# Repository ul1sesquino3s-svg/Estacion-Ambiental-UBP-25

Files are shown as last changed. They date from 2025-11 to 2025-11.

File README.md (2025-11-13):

# Estacion-Ambiental-UBP-25

Repositorio del proyecto de Lab-I con Arduino UNO: Estación Ambiental Inteligente con sensores y módulos

Integrantes del proyecto: Ignacio Alzabé, Donato Doebbeling, Ulises Carlos Quiñones, Juan Manuel Servadei

Profesores:

Teórico: Ing. Martín Salamero

Práctico: Prof. Aguero y Prof. Escudero

## **Cosas Importantes**

**Lectura de los archivos CSV**
Cada linea tiene la fecha y la hora, y los números que hay corresponden a la temperatura, humedad del aire, luminosidad y humedad

de la tierra, respectivamente.

**App Bluetooth**

Se abre la app, debe elegirse el módulo previamente emparejado llamada *GORDATO*, luego se presiona "Conectar" y se espera un minuto

hasta que se envien por primera vez los datos en el módulo.

**LCD I2C**

Todos los sensores mostrarán 0 en sus lecturas durante el primer minuto; esto forma parte del funcionamiento esperado, ya que

los datos se actualizan cuando se cargan en el archivo csv, que ocurre cada 60 segundos.

**Contenido del Repositorio**

Presentación utilizada durante la exposición

Archivo CSV del día 22 de octubre, uno de los días los cuales se hizo la prueba de 48hs.

Informe completo del proyecto

Bitácoras de todo el progreso del proyecto

Código en .ino del proyecto y backup en .txt

Archivo STL de la carcasa creada para el proyecto

README

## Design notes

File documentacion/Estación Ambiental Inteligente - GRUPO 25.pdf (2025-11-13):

Proyecto Arduino: Estación Ambiental Inteligente

GRUPO 25: Ignacio Alzabé, Donato Doebbeling, Ulises Quiñones, Juan Manuel Servadei

Prof. Martín Salamero

Universidad Blas Pascal

14 de noviembre de 2025

ÍNDICE

INTRODUCCIÓN

Nuestro objetivo de todo el semestre fue crear una estación ambiental propia, con código propio y aprendiendo paso a paso en el camino. Al igual que los demás grupos, los materiales con los que iniciamos fueron:
- Arduino UNO
- Protoboard
- Cables macho-macho, hembra-hembra, macho-hembra
- Fotorresistor LDR
- Sensor DHT11 (Humedad y Temperatura)
- Sensor opcional de humedad de la tierra
- Clock RTC DS1302
- Resistencias de 1k ohm
- Pantalla LCD I2C 16x2
- Lector de tarjetas SD
- Módulo Bluetooth HC-05

Nuestra plataforma de organización fue Microsoft Teams, donde fuimos escribiendo nuestras bitácoras día a día y en los Mensajes Directos están todas nuestras iteraciones de código, hasta las más mínimas.

En el tiempo dado, pudimos armar, codificar, probar y finalizar un prototipo completo de una Estacion Ambiental Inteligente, donde se registran datos como: Temperatura, Humedad del suelo y de la tierra (donde sea que se lo plante al sensor), luminosidad, y grabar todos los datos en una tarjeta SD con una duración estimada de 5 años de almacenamiento.

DESARROLLO
Información de sensores
Fotorresistor LDR
Su nombre proviene del inglés y significa resistor dependiente de la luz. Esto significa que el valor de la resistencia depende de la luz que esté recibiendo. Gracias a esto, se puede transformar con Arduino IDE el valor que recibe a un porcentaje para medir la luz en un ambiente, por ejemplo. También puede usarse para detectar cuando pasan personas por una puerta. Tienen solo dos patas, por lo que deben conectarse en serie con otras resistencias.

Sensor DHT11
Es uno de los sensores más usados y conocidos para trabajar con Arduino. Tiene una alta estabilidad y fiabilidad, pero una de sus desventajas es que sus patas son muy finas. Esto puede llevar a problemas en la señal si no se conectan adecuadamente. Mide temperatura y humedad del aire, y transmite ambos datos por pin analógico. Tiene una versión con PCB, que integra una resistencia pull up. Necesita una librería para configurarlo.

Sensor de humedad del suelo
Comprado en MercadoLibre, tiene dos electrodos y un módulo con led de conexión y de alta humedad integrado. Funciona midiendo la capacidad de la tierra para transmitir electricidad, y gracias a eso, calcular el agua presente en el suelo y convertirlo a voltaje. Está conectado a una salida analógica.

Reloj RTC DS1302
Tiene la capacidad de llevar el tiempo con el poder desconectado gracias a una pila CR2025 o CR2032. Necesita una librería para configurarlo.

Pantalla I2C 16x2
Muestra todos los datos de los sensores y la fecha y hora en el Arduino. Tiene un módulo i2c conectado detrás para reducir la cantidad de pines necesarios. En nuestro caso particular, la dirección donde se encuentra es 0x26, pero la más común es 0x27.

Lector de tarjetas SD
Gracias a la librería SD de arduino, puede cargar los datos de los sensores en un archivo csv cada cierta cantidad de tiempo. En nuestro caso, cada minuto.

Módulo Bluetooth HC-05
Módulo con SLAVE y MASTER, usado para transmitir datos desde el Arduino hasta nuestra app para celulares creada en Mit App Inventor.

Primeras versiones del código

Lo primero fue la investigación; aplicando lo que nos habían enseñado hasta ahora, conectamos los sensores a los cables y estos a los distintos puertos del Arduino. Revisamos en internet, y en páginas de los sensores, distintos códigos de prueba para verificar el funcionamiento de cada uno de los mismos.
La primera dificultad que nos encontramos fue cuando detectamos que el DHT11 no funcionaba, creímos que fue porque estaba defectuoso o dañado, por lo que fue reemplazado por otro comprado fuera del laboratorio. Este nuevo sensor, a diferencia del anterior, requería dos resistencias externas para funcionar, que agregamos en la protoboard para realizar la señal.

Con el nuevo sensor, escribimos un código inicial que hacía esto:
- Iniciaba el LCD y el sensor DHT11
- Leía los valores de temperatura y humedad cada 5 segundos.
- Mostraba alternativamente en el LCD dichos valores, con mensajes simples
- Implementa una verificación de errores para evitar mostrar valores inválidos (isnan)

Este prototipo nos permitió validar que el Arduino pudiese interactuar correctamente con el sensor y el display.

Código inicial

#include <Wire.h>

#include <LiquidCrystal_I2C.h> #include <DHT.h>

#define DHTPIN 5

#define DHTTYPE DHT11

DHT dht(DHTPIN, DHTTYPE);

LiquidCrystal_I2C lcd(0x26, 16, 2);

void setup() {
lcd.init();
lcd.backlight();
dht.begin();
}

void loop() {

delay(5000);
float h = dht.readHumidity();
float t = dht.readTemperature();

if (isnan(h) || isnan(t)) {
lcd.print("Error obteniendo los datos del sensor DHT11"); return;
}

lcd.clear();
lcd.setCursor(0, 0);
lcd.print("Humedad:");
lcd.setCursor(10, 0);
lcd.print(h);
lcd.print("%");
delay(5000);

lcd.clear();
lcd.setCursor(0, 0);
lcd.print("Temp:");
lcd.setCursor(10, 1);
lcd.print(t);
lcd.print(" C");
delay(5000);
}

Explicacion del codigo

#include <Wire.h>

#include <LiquidCrystal_I2C.h>

#include <DHT.h>

- Wire.h : permite la comunicación 12C entre el Arduino y otros dispositivos
- LiquidCrystal_I2C.h : Controla la pantalla LCD utilizando solo dos pines mediante I2C.
- DHT.h : Permite leer datos del sensor DHT11

Definición del sensor:

#define DHTPIN 5

#define DHTTYPE DHT11

DHT dht(DHTPIN, DHTTYPE);
- Acá se define el pin digital 5 como el pin de datos del sensor.

- Se indica que se está utilizando un DHT11
- Se crea un objeto “dht” para manejar las lecturas del sensor

Inicializacion del display y el sensor:

LiquidCrystal_I2C lcd(0x26, 16, 2);

void setup() {
lcd.init(); | // Inicializa la pantalla
lcd.backlight(); | // Enciende la luz de fondo del LCD
dht.begin(); | // Inicia el sensor DHT11
}
- El LCD tiene dirección “0x26” y es de 2 filas por 16 columnas.
- En setup() se inicializan ambos periféricos para que estén listos para usarse

Lógica principal (Loop):

void loop() {
delay(5000); // Espera 5 segundos entre cada ciclo
- Se utiliza una espera inicial para evitar lecturas demasiado seguidas
float h = dht.readHumidity(); | // Lee la humedad (%)
float t = dht.readTemperature(); | // Lee la temperatura (°C)
- Las lecturas se almacenan como variables Float para poder mostrar los decimales

if (isnan(h) || isnan(t)) {
lcd.print("Error obteniendo los datos del sensor DHT11");
return;
}
- Si alguna lectura falla, se muestra un mensaje de error y se interrumpe el ciclo actual.

float hic = dht.computeHeatIndex(t, h);

- A pesar de que no se muestre en pantalla, se calcula el índice de calor usando la temperatura y la humedad

Mostrar humedad:

lcd.clear();
lcd.setCursor(0, 0);
lcd.print("Humedad:");
lcd.setCursor(10, 0);
lcd.print(h);
lcd.print("%");
delay(5000);
- Limpia la pantalla, escribe “Humedad:” y luego muestra el valor leído seguido de “%”
- Espera 5 segundos antes de cambiar la pantalla

Mostrar temperatura:

lcd.clear();
lcd.setCursor(0, 0);
lcd.print("Temp:");
lcd.setCursor(10, 1);
lcd.print(t);
lcd.print(" C");
delay(5000);
}
- Limpia la pantalla, muestra “Temp:” y el valor de temperatura seguido de “°C”
- Espera 5 segundos antes de reiniciar el bucle

Etapa 2

Ese mismo día, avanzamos hubo una mejora del código. Incorporaba un sensor de luz analogico (LDR) conectado al pin A0

En esta versión del código se mantuvo el DHT11 para leer la temperatura y humedad, se agregó una lectura analógica desde el LDR, usando “analogRead(A0)”. Se implementó la función map() para convertir el valor leído (entre 0 y 1023) Se programó que el LCD muestre tres variables secuencialmente (Humedad, Temperatura y Nivel de luz)

Esta versión fue importante porque empezamos a implementar múltiples sensores y a experimentar con la secuencia de visualización en pantalla.

Segundo código
#include <Wire.h>

#include <LiquidCrystal_I2C.h> #include <DHT.h>

#define DHTPIN 5

#define DHTTYPE DHT11

DHT dht(DHTPIN, DHTTYPE);
const int sensorluz = A0;

LiquidCrystal_I2C lcd(0x26, 16, 2);

void setup() {
lcd.init();
lcd.backlight();
dht.begin();
}

void loop() {
delay(1000);

float h = dht.readHumidity();
float t = dht.readTemperature();

int valorluz = analogRead(sensorluz);
int porcentajeluz = map(valorluz, 0, 1023, 0,100);

if (isnan(h) || isnan(t)) {
lcd.print("Error obteniendo los datos del sensor DHT11"); return;
}

float hic = dht.computeHeatIndex(t, h);

lcd.clear();
lcd.setCursor(0, 0);
lcd.print("Humedad:");
lcd.setCursor(10, 0);
lcd.print(h);
lcd.print("%");
delay(5000);

lcd.clear();
lcd.setCursor(0, 0);

lcd.print("Temp:");
lcd.setCursor(10, 0);
lcd.print(t);
lcd.print(" C");
delay(5000);

lcd.clear();
lcd.setCursor(0, 0);
lcd.print("Luz:");
lcd.setCursor(10, 0);
lcd.print(porcentajeluz);
lcd.print("%");
delay(1000);
}

Explicacion del codigo (Solo lo añadido)
int valorluz = analogRead(sensorluz);
- Se realiza una lectura analogica desde el pin A0, que entregas valores entre 0 y 1023
int porcentajeluz = map(valorluz, 0, 1023, 0, 100);
- Se usa la función map() para transformar la lectura a un porcentaje inverso
- 0%: máxima oscuridad
- 100%: máxima luz

lcd.clear();
lcd.setCursor(0, 0);
lcd.print("Luz:");
lcd.setCursor(10, 0);
lcd.print(porcentajeluz);
lcd.print("%");
delay(1000);
- Se agregó una tercera pantalla al ciclo de visualización
- Muestra el porcentaje de luz y luego se espera 1 segundo antes de reiniciar el bucle

Etapa 3

En esta nueva versión del código, se incorporó el modulo RTC DS1302, que nos permitió disponer de una referencia horaria confiable y permanente, independientemente del estado de alimentación del Arduino.

Además, reorganizamos completamente la forma en el que se muestran los datos en la pantalla LCD, dividiéndose en dos grupos de variables, por un lado las variables de los sensores y por el otro la fecha y hora , que estos se muestran en la pantalla LCD y alternan sus valores cada 5 segundos.

Código tres, RTC y organización

// BETA ESTACION AMBIENTAL

#include <Wire.h>

#include <LiquidCrystal_I2C.h>

#include <DHT.h>

#include <RtcDS1302.h>

#define DHTPIN 5

#define DHTTYPE DHT11

DHT dht(DHTPIN, DHTTYPE);

const int sensorluz = A0;

const int sensorhumt = A2;

LiquidCrystal_I2C lcd(0x26, 16, 2);

ThreeWire myWire(4, 5, 2); // IO, SCLK, CE

RtcDS1302<ThreeWire> Rtc(myWire);

// ---- control de tiempos ----unsigned long previousMillisRTC = 0;

unsigned long previousMillisSensors = 0;

const unsigned long intervalRTC = 1000; // refrescar hora cada 1s

const unsigned long intervalSensors = 5000; // alternar sensores cada 5s

bool mostrarGrupo1 = true;

void setup() {

Serial.begin(9600);

lcd.init();

lcd.backlight();

dht.begin();

delay(2000);

// Inicializar el RTC

Rtc.Begin();

delay(1000);

// Setear fecha/hora de compilación (solo como ejemplo)

RtcDateTime compiled = RtcDateTime(__DATE__, __TIME__);

Rtc.SetDateTime(compiled);

if (Rtc.GetIsWriteProtected()) {

Rtc.SetIsWriteProtected(false);

}

}

void loop() {

unsigned long currentMillis = millis();

// --- actualizar hora cada 1s ---

if (currentMillis - previousMillisRTC >= intervalRTC) {

previousMillisRTC = currentMillis;

RtcDateTime now = Rtc.GetDateTime();

printTime_LCD(now);

}

// --- alternar sensores cada 5s ---

if (currentMillis - previousMillisSensors >= intervalSensors) {

previousMillisSensors = currentMillis;

// limpiar primera línea

lcd.setCursor(0, 0);

lcd.print(" | ");

if (mostrarGrupo1) {

// Grupo 1: humedad suelo + luz

int valorluz = analogRead(sensorluz);

int porcentajeluz = map(valorluz, 0, 1023, 0, 100);

int valorhumedadt = analogRead(sensorhumt);

int porcentaje hunt = map(valorhumedadt, 365, 1023, 100, 0);

lcd.setCursor(0, 0);

lcd.print("HS:");

lcd.print(porcentajehumt);

lcd.print("%");

lcd.setCursor(7, 0);

lcd.print("Luz:");

lcd.print(porcentajeluz);

lcd.print("%");

} else {

// Grupo 2: temperatura + humedad aire

float h = dht.readHumidity();

float t = dht.readTemperature();

lcd.setCursor(0, 0);

lcd.print("T:");

lcd.print((int)t); // entero para que entre

lcd.print((char)223); // símbolo de grados °

lcd.print("C");

lcd.setCursor(8, 0);

lcd.print("HA:");

lcd.print((int)h);

lcd.print("%");

}

mostrarGrupo1 = !mostrarGrupo1; // alternar

}

}

void printTime_LCD(const RtcDateTime& dt) {

char datestring[9]; // HH:MM:SS

snprintf_P(datestring, sizeof(datestring),

PSTR("%02u:%02u:%02u"),

dt.Hour(), dt.Minute(), dt.Second());

lcd.setCursor(7, 1);

lcd.print(datestring);

}

Explicacion del codigo, solo lo nuevo:

#include <RtcDS1302.h>

- Se utiliza la librería RtcDs1302.h

ThreeWire myWire(4, 5, 2); // IO, SCLK, CE RtcDS1302<ThreeWire> Rtc(myWire);

- Se utiliza la interfaz “TrheeWire” para manejar el reloj de tiempo real.

RtcDateTime compiled = RtcDateTime(__DATE__, __TIME__); Rtc.SetDateTime(compiled);
- En el setup(), se carga la fecha/hora de compilación como valor inicial
- Esto se hace una sola vez para sincronizar el reloj interno, luego queda funcionando de forma autónoma

printTime_LCD(now);

- Cada segundo, se actualiza el reloj usando esa línea
- El tiempo se muestra en la segunda fila del LCD con el formato HH:MM:SS

Ciclo de visualización alternado

bool mostrarGrupo1 = true;

- Se alternan dos grupos de datos en la primera fila de LCD, cada 5 segundos:
- Grupo 1:
- HS: Humedad del suelo
- Luz: Nivel de luz
- Grupo 2:
- T: Temperatura ambiente
- HA: Humedad ambiente
- Se utilizó una bandera booleana “mostrarGrupo1” para alternar entre ambos grupos

Este diseño simplifica la interfaz y permite mostrar mas informacion con un solo display de 16x2 sin saturar

Control por temporizadores:

if (currentMillis - previousMillisRTC >= intervalRTC)

- Se reemplazó el uso de delau() por un control manual del tiempo con millis(), lo que permite ejecutar tareas en paralelo sin bloquear el programa
- Esto fue clave para poder actualizar sensores y reloj a diferentes intervalos sin conflictos.

Con esta versión logramos una visualización organizada. Integramos el RTC DS1302 que nos permitió que el proyecto de un salto de calidad: ahora puede registrar eventos o variables con una referencia temporal real, esencial para la futura integración con la tarjeta SD y el registro de datos históricos.

Etapa 4

En esta etapa del desarrollo, implementamos el sensor de humedad y avanzamos hacia uno de los objetivos fundamentales del proyecto: registrar los datos medidos en archivos CSV, almacenados en una tarjeta microSD, con su respectiva marca temporal obtenida del módulo RTC.

Este paso permitió que la estación ambiental ya no solo mostrará datos en tiempo real, sino que pudiera registrarlos de forma histórica para su posterior análisis.

Agregados nuevos

Inicialización del módulo SD

#include <SD.h>

#include <SPI.h>

if (!SD.begin(10)) {
Serial.println("Fallo al inicializar SD.");
return;
}
- Se utilizó la librería SD.h para manejar el almacenamiento
- El módulo se inicializa en el pin 10
- Si la tarjeta no es detectada correctamente, el programa muestra un mensaje aborta la operación

Creación del nombre de archivo

sprintf(nombreArchivo, "LOG_%04u%02u%02u.CSV", ahora.Year(), ahora.Month(), ahora.Day());

- Se crea un archivo diferente por cada día de funcionamiento
- El nombre tiene el formato “LOG_AAAAMMDDD.CSV”

Formateo de timestamp con RTC

sprintf(tiempoBuffer, "%04u/%02u/%02u %02u:%02u:%02u", ...);

- Se construye una cadena con la fecha y hora actual.
- Se almacena en “tiempoBuffer” que luego se utiliza tanto para mostrar en LCD como para registrar en el archivo

Lectura de sensores y escrituras en SD

sprintf(cargardatos, "%s,%d,%d,%d,%d", tiempoBuffer, t, h, porcentajeluz, porcentajehumedadt);
myFile = SD.open(nombreArchivo, FILE_WRITE);
- Cada 60 segundos se actualizan las lecturas de los sensores
- Los valores se combinan con el timestamp en una línea CSV.
- La línea se escribe en el archivo correspondiente al día actual

Visualización dual mejorada

- Ahora cada 3 segundos la pantalla LCD alterna entre:
- Pantalla 1: Muestra las cuatro variables
- Pantalla 2: Muestra la fecha y la hora

Con esta versión alcanzamos un prototipo casi completo y autónomo, capaz de medir, mostrar y registrar datos ambientales de forma continua y confiable.
Etapa final, finalizacion del código

En esta versión final, se completó el ciclo completo del proyecto: Medir,mostrar,registrar y transmitir datos ambientales en tiempo real, de forma autónoma y continua. También, se hizo una aplicación en “MIT App Inventor” para que pueda recibir los datos que da el Arduino.

La principal novedad es la integración del módulo Bluetooth HC-05, que permite enviar los datos a un celular que tenga la aplicación que desarrollamos. Esto transforma la estación en un sistema de monitoreo en vivo.

Código final

Visible en repositorio de GIT

Lo nuevo

#include <SoftwareSerial.h> SoftwareSerial BT(7, 8); // RX, TX

BT.begin(9600);
BT.println("HC-05 listo");
- Se utiliza la librería “SoftwareSerial” para crear un puerto serie adicional en los pines 7 y 8
- Al encender la estación, se envía un mensaje de bienvenida a la app
- Este mensaje inicial también sirve para comprobar que la conexión está activa

BT.println(cargardatos);

- Esto permite visualizar en tiempo real las variables ambientales sin tener que abrir el archivo o conectar el Arduino a una PC.
- Si ocurre un error al guardar la tarjeta SD, también se avisa por bluetooth

BT.println("ERROR_SD");

- Esto mejora la detección de fallas

Mejoras finales

Se implementó una función llamada “abrirArchivoNuevo()” que verifica si el archivo diario está abierto y lo reabre automáticamente si es necesario. También, se añadieron mecanismos de recuperación ante fallos en la tarjeta SD, como un reinicio del bus SPI, intentar abrir el archivo de nuevo y por último un Fallback con mensaje de error.

A lo largo de las distintas etapas, el código evolucionó desde una simple lectura de sensores hasta un sistema integrado de monitoreo ambiental inteligente, con funcionalidades:
- Sensor de temperatura y humedad del aire
- Sensor de luz
- Sensor de humedad del suelo

- Registro de datos en tarjeta SD
- Visualización cíclica en pantalla LCD
- Control de fecha/hora con RTC DS1302
- Comunicación Bluetooth en tiempo real
Se logró una estación autónoma capaz de operar más de 48 horas sin intervención.

CONCLUSIÓN

A lo largo del proyecto, nuestro grupo logró desarrollar una estación de monitoreo ambiental inteligente completamente funcional, capaz de operar de forma autónoma durante más de 48 horas. El proceso de desarrollo no fue lineal. Tuvimos que investigar sobre todo los sensores, como funcionan y cómo se conectan. Fue una prueba, error y corrección constante, y un fuerte trabajo colaborativo que fue moldeando el producto final.

Comenzamos con un código muy simple que solo leía temperatura y humedad del aire (Con el DHT11), y lo mostraba por la pantalla. A medida que fuimos investigando y aprendiendo de los componentes, fuimos incorporando nuevas funcionalidades claves, como la lectura de luz, humedad del suelo, gestión horaria con un reloj RTC, guardado automático de datos en archivos CSV y, finalmente, comunicación en tiempo real por Bluetooth hacia una aplicación móvil diseñada por nosotros mismos.

Además de integrar varios sensores y módulos distintos, aplicamos principios de programación eficientes, tales como el uso de millis() para evitar bloqueos, estructuras condicionales para la rotación de pantallas, verificación de errores en sensores y tarjetas SD, y funciones especificas como “abrirArcvhioNuevo()” para lograr un sistema robusto y tolerante a fallos.

El resultado es un dispositivo modular, portátil y confiable, capaz de medir en simultáneo cinco variables distintas, como la temperatura, humedad del aire, humedad del suelo, nivel de luz y fecha/hora. Todos estos datos se visualizan, registran y transmiten sin necesidad de una intervención humana.

Este proyecto nos permitió aplicar lo aprendido en clase y enfrentarnos a problemas reales que nos obligaron a buscar soluciones, debatir ideas y trabajar como equipo. Más allá de lo técnico, fue una experiencia formativa que refuerza nuestras habilidades en programación, electrónica, diseño de sistemas y documentación.

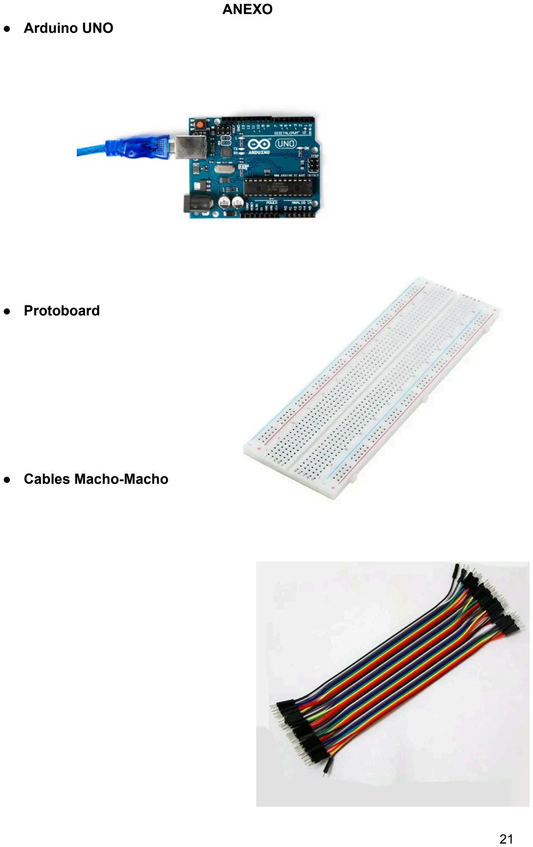
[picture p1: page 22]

ANEXO
- Arduino UNO
- Protoboard
- Cables Macho-Macho

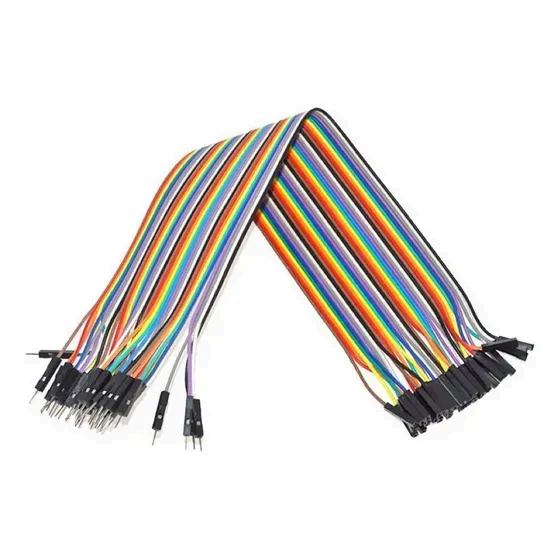
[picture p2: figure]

- Cables Macho-Hembra

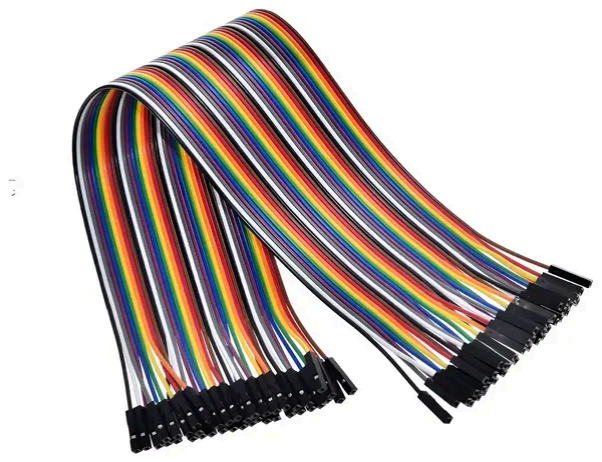
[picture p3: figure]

- Cables Hembra-Hembra

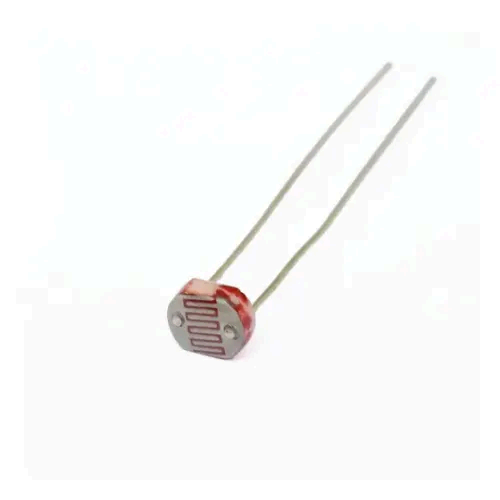
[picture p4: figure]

- Fotorresistor LDR
- Sensor DHT11 (Humedad y Temperatura)

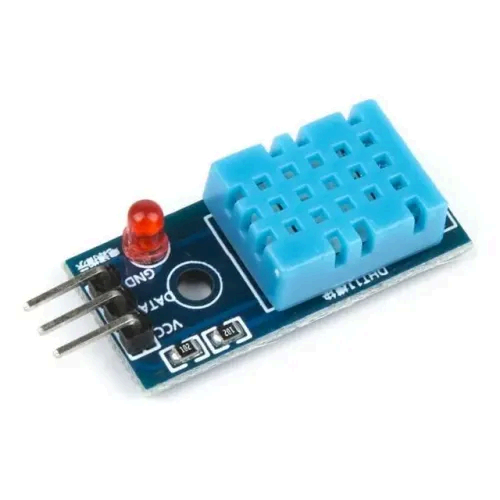
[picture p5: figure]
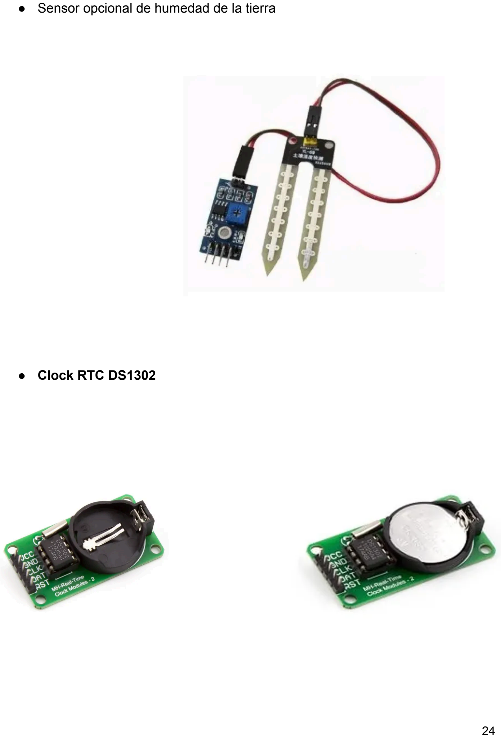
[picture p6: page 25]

- Sensor opcional de humedad de la tierra
- Clock RTC DS1302

- Resistencias de 1k ohm
- Pantalla LCD
I2C 16x2

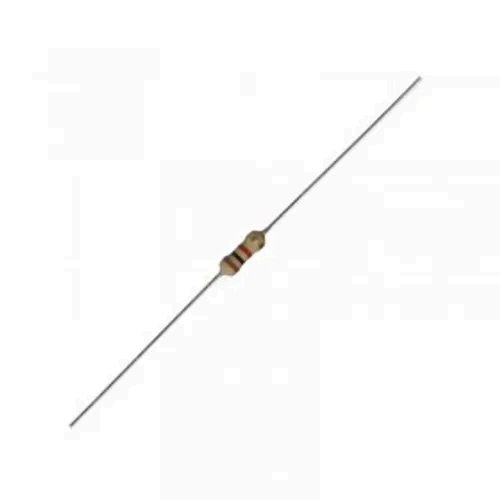
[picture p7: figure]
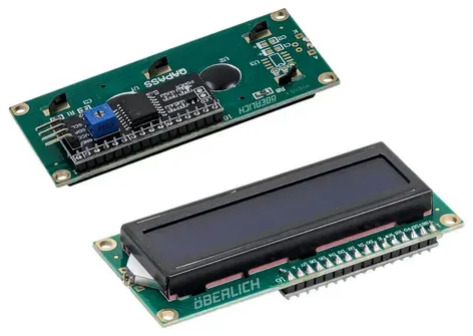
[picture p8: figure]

- Lector de tarjetas SD

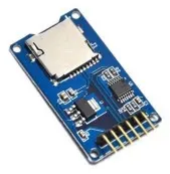
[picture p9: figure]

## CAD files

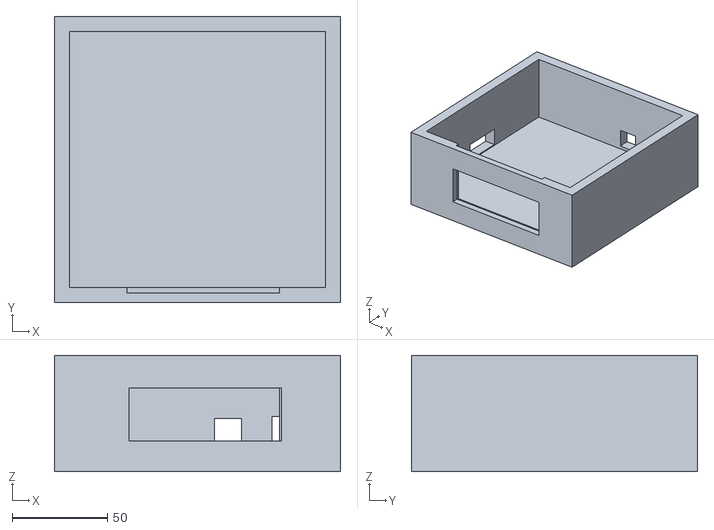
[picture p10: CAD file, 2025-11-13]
hardware/Carcasa_Estacion.stl
150.0 x 150.0 x 61.0

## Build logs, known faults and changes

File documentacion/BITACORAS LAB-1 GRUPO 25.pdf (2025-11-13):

Archivo de bitácoras
Estacion Ambiental Inteligente con Arduino Grupo 25
Quiñones - Doebbeling - Servadei - Alzabé

Bitácora del día 1 (07/08/2025) - General
Conformación del grupo:
Ignacio Alzabe, Donato Doebbeling, Ulises Quiñones, Juan Manuel Servadei
Sensor opcional elegido:
Sensor de humedad del suelo para placa arduino. Link de ML: https://articulo.mercadolibre.com.ar/MLA-759326593-sensor-humedad-suelo-arduino-modulo-higrometro-tierra-_JM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 (https://articulo.mercadolibre.com.ar/MLA-759326593-sensor-humedad-suelo-arduino-modulo-higrometro-tierra-_JM)
Alguna de sus características son:
Posee 2 salidas: 1 digital que indica si la humedad está por arriba o debajo de un nivel prefijado mediante el preset y 1 analógica que indica la humedad del suelo por medio de un valor de tensión que varía entre 0V y la tensión de alimentación (la tensión disminuye con la humedad del suelo).
Como programar:
https://www.automatizacionparatodos.com/sensor-de-humedad-de-suelo-con-arduino/

Bitácora del día 2 (14/08/25) - Ulises
Pruebas en Tinkercad:

Realizamos distintas pruebas con el simulador "Tinkercad" para visualizar el funcionamiento de la placa junto con los sensores.
En primer lugar, conectamos el sensor obligatorio de temperatura, lo programamos con ayuda de Internet y funcionó perfectamente en el monitor serial. Luego, conectamos una pantalla LCD en el Arduino para poder enviar la información a través de una pantalla digital, un objetivo que tenemos para más adelante. También experimentamos con el sensor de humedad del suelo, pero tenemos que mejorar el código para que funcione correctamente.

Ideas:

Surgió la idea de usar botones en nuestra estación, para alternar la información que el LCD muestra de cada uno de los sensores, hicimos algunas pruebas pero tenemos que refinar la idea. Empezamos también a ver cómo será la plataforma donde estarán la placa y los sensores.

Bitácora del día 3 - (28/08/2025) - General
Trabajando en el Arduino

Durante estas 3 semanas, logramos pasar lo que habíamos probado en Tinkercad al Arduino Uno físico. Compramos nuestro sensor de humedad del suelo y un sensor DHT11 de temperatura, para sustituir el que se quemó. Después, conectamos de a poco los sensores mientras experimentamos con la pantalla I2C. Hoy en el laboratorio logramos finalmente integrar los 3 sensores (DHT11, Humedad del suelo, fotorresistor) junto al clock y mostrar todo en el LCD, alternando el primer renglón para que muestre Temperatura y Humedad, y, pasados 3 segundos, Humedad del suelo y luz. Todo funciona, aunque el código aún no está listo y presenta errores de vez en cuando si lo alteramos. Como próximo objetivo queda mejorar la distribución de los cables, agregar memoria para registrar en un archivo cada x tiempo, y optimizar el código para prolongar la vida útil de los sensores.

Bitácoras del día 4 (04/08) al día 8 (02/10) - General
Conectando y programando
Durante todo el mes de agosto y el de septiembre, nos dedicamos a refinar nuestro código, mejorar el cableado e integrar tanto el RTC (Real Time Clock) como el lector de tarjetas SD. Lo primero que hicimos fue integrar el reloj y meter todos los datos de los sensores dentro de la pantalla del I2C, para que, pasados 3 segundos, se muestre la fecha y la hora actuales. Tuvimos una serie de problemas con el reloj que fueron solucionados luego de implementar algunos ifs y seguridad al código (por ejemplo, que detecte cuando la hora está desincronizada y la actualice). Después integramos el lector de SD y comenzaron problemas más grandes.
Resolviendo el problema de la SD
Desde que lo integramos al circuito entero, comenzamos a experimentar problemas tanto de cableado como de código en general. Nuestro código no estaba adaptado para tener distintos tiempos de procesamiento (necesitábamos cargar datos en la SD cada 60 segundos y mostrar datos en pantalla cada 3) por lo que le hicimos una reestructuración profunda, implementando la lógica de tiempo millis().
Más tarde, tuvimos problemas al ejecutar todo el sistema al mismo tiempo, creímos que podía deberse a una débil fuente de poder, pero luego de cambiarla, todo siguió igual.

Más adelante descubrimos que un error en nuestro código, específicamente en la función que trabajaba con la SD, la abría y cerraba en cada ciclo del loop. Eso provocaba un congelamiento total de todo el programa, un problema que nos costó otra reforma del código y mejores medidas de seguridad.

Bitácora del día 9 (09/10)
Durante este día nos dedicamos a probar mejoras temporales (como reabrir el archivo cada unos minutos, usar sd.flush para no perder datos, cambiar la función de la SD) para terminar el funcionamiento de este módulo. Finalmente implementamos una lógica que cargaba los datos de los sensores en la SD cada 1 minuto, luego cerraba y abria el archivo cada 2 minutos para no perder datos en caso de una pérdida de voltaje, y al mismo tiempo mostraba los datos de los sensores cada 3 segundos en el I2C.

Bitácora del día 10 (16/10)

Temprano en la mañana descubrimos un error en la protoboard que provocaba una lectura errónea tanto del fotorresistor (LDR) como del sensor de humedad del suelo. Luego de algunos intentos creyendo que el problema era de los sensores, lo descubrimos. Se trataba de que no habíamos hecho un puente de una mitad a otra de la protoboard, lo que comenzó a causar problemas cuando modificamos la ubicación de todos los sensores. Lo corregimos y ambos sensores volvieron a su funcionamiento normal.
A una hora de terminar el día, el serial monitor comenzó a arrojar errores al intentar cargar la línea CSV en el archivo y nuevamente se congelaba el código. No entendíamos a qué se debía, por lo que implementamos algunos bucles para que el sistema intentara ingresar los archivos al CSV. Como el problema ocurría cada unos 6 o 7 minutos, creímos haberlo solucionado y nos retiramos del aula.

Bitácora del día 11 (22/10)
Durante el fin de semana comenzamos nuestra prueba preliminar de las 48 horas seguidas de funcionamiento, para encontrarnos con que el problema no se había solucionado. El archivo seguía fallando luego de unos minutos incluso cuando el sistema reintentaba ingresar los datos. Al llegar al aula, eliminamos la función que abría y cerraba el archivo cada 2 minutos (ahora el archivo solo se cierra al finalizar un día) y parece haber funcionado. Esta tarde comprobaremos si fue exitoso o no.

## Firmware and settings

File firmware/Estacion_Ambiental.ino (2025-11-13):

// ESTACIÓN AMBIENTAL V2
#include <Wire.h>
#include <LiquidCrystal_I2C.h>
#include <DHT.h>
#include <RtcDS1302.h>
#include <SD.h>
#include <SPI.h>
 
#include <SoftwareSerial.h>  
 
#define DHTPIN 6
#define DHTTYPE DHT11
DHT dht(DHTPIN, DHTTYPE);
 
int t = 0;
int h = 0;
int porcentajeluz = 0;
int porcentajehumedadt = 0;
int estadopantalla = 0;
 
char tiempoBuffer[20];
char nombreArchivo[13];
File myFile;
 
const int sensorluz = A0;
const int sensorhumt = A2;
 
unsigned long tiempoanteriorpantalla = 0;
const unsigned long tiempopantalla = 3000;
 
unsigned long tiempoanteriorrtc = 0;
const unsigned long tiemportc = 3000;
 
unsigned long tiempoanteriorarchivo = 0;
const unsigned long tiempoarchivo = 60000;  
 
LiquidCrystal_I2C lcd(0x26, 16, 2);
 
ThreeWire myWire(4, 5, 2); // IO, SCLK, CE
RtcDS1302<ThreeWire> Rtc(myWire);
RtcDateTime ahoraAnterior;
 
SoftwareSerial BT(7, 8); // RX, TX
 
 
void abrirArchivoNuevo(RtcDateTime ahora) {
  if (myFile) {
    myFile.close();
  }
 
  sprintf(nombreArchivo, "%04u%02u%02u.CSV",
          ahora.Year(),
          ahora.Month(),
          ahora.Day());
 
  myFile = SD.open(nombreArchivo, FILE_WRITE);
 
  if (!myFile) {
    Serial.print(F("Fallo al abrir archivo: "));
    Serial.println(nombreArchivo);
 
    // Recuperación del bus SPI y SD
    Serial.println(F("Reiniciando bus SD..."));
    SD.end();
    delay(200);
    if (SD.begin(10)) {
      Serial.println(F("SD re-inicializada correctamente."));
      myFile = SD.open(nombreArchivo, FILE_WRITE);
 
      if (myFile) {
        Serial.println(F("Archivo reabierto exitosamente tras reiniciar SD."));
      } else {
        Serial.println(F("Fallo al reabrir archivo después de reiniciar SD."));
      }
    } else {
      Serial.println(F("Fallo total: no se pudo re-inicializar SD."));
    }
  } else {
    Serial.print(F("Archivo abierto: "));
    Serial.println(nombreArchivo);
  }
}
 
void setup() {
  Serial.begin(9600);
 
  BT.begin(9600);                // agregado: inicializar el HC-05 en modo normal
  BT.println("GORDATO listo "); // mensaje inicial al celular
 
  lcd.init();
  lcd.backlight();
 
  dht.begin();
 
  Rtc.Begin();
  RtcDateTime compiled = RtcDateTime(__DATE__, __TIME__);
 
  if (!Rtc.IsDateTimeValid()) {
    Rtc.SetDateTime(compiled);
  }
 
  if (!Rtc.GetIsRunning()) {
    Rtc.SetIsRunning(true);
  }
 
  if (Rtc.GetIsWriteProtected()) {
    Rtc.SetIsWriteProtected(false);
  }
 
  Serial.println("Inicializando SD...");
  pinMode(10, OUTPUT);
  if (!SD.begin(10)) {
    Serial.println("Fallo al inicializar SD.");
    while (1);
  }
  Serial.println("Inicialización exitosa.");
 
  RtcDateTime ahora = Rtc.GetDateTime();
  ahoraAnterior = ahora;
  abrirArchivoNuevo(ahora);
}
 
void loop() {
  unsigned long tiempoactual = millis();
 
  // ACTUALIZACIÓN DEL RTC
  if (tiempoactual - tiempoanteriorrtc >= tiemportc) {
    tiempoanteriorrtc = tiempoactual;
 
    RtcDateTime ahora = Rtc.GetDateTime();
 
    // Verifica si cambió el día
    if (ahora.Day() != ahoraAnterior.Day() ||
        ahora.Month() != ahoraAnterior.Month() ||
        ahora.Year() != ahoraAnterior.Year()) {
      ahoraAnterior = ahora;
      abrirArchivoNuevo(ahora);
    }
 
    sprintf(tiempoBuffer,
            "%04u/%02u/%02u %02u:%02u:%02u",
            ahora.Year(),
            ahora.Month(),
            ahora.Day(),
            ahora.Hour(),
            ahora.Minute(),
            ahora.Second());
 
    Serial.print(F("RTC actualizado en buffer: "));
    Serial.println(tiempoBuffer);
  }
 
  // MOSTRAR EN LCD
  if (tiempoactual - tiempoanteriorpantalla >= tiempopantalla) {
    tiempoanteriorpantalla = tiempoactual;
 
    lcd.clear();
    if (estadopantalla == 0) {
      lcd.setCursor(0, 0);
      lcd.print("T:");
      lcd.print(t);
      lcd.print("C");
 
      lcd.setCursor(7, 0);
      lcd.print("HA:");
      lcd.print(h);
      lcd.print("%");
 
      lcd.setCursor(0, 1);
      lcd.print("HS:");
      lcd.print(porcentajehumedadt);
      lcd.print("%");
 
      lcd.setCursor(7, 1);
      lcd.print("Luz:");
      lcd.print(porcentajeluz);
      lcd.print("%");
 
      estadopantalla = 1;
    } else {
      lcd.setCursor(0, 0);
      for (int i = 0; i < 10; i++) {
        lcd.print(tiempoBuffer[i]);
      }
      lcd.setCursor(0, 1);
      lcd.print(&tiempoBuffer[11]);
      estadopantalla = 0;
    }
  }
 
  // LECTURA Y ESCRITURA CADA 1 MINUTO (60,000 ms)
  if (tiempoactual - tiempoanteriorarchivo >= tiempoarchivo) {
    tiempoanteriorarchivo = tiempoactual;
 
    h = dht.readHumidity();
    t = dht.readTemperature();
 
    int valorluz = analogRead(sensorluz);
    porcentajeluz = map(valorluz, 0, 1023, 0, 100);
 
    int valorhumedadt = analogRead(sensorhumt);
    porcentajehumedadt = map(valorhumedadt, 600, 1023, 100, 0);
 
    char cargardatos[80];
    sprintf(cargardatos,
            "%s,%d,%d,%d,%d",
            tiempoBuffer,
            t,
            h,
            porcentajeluz,
            porcentajehumedadt);
 
    // VERIFICAR ARCHIVO Y REINTENTAR SI FALLA
    if (myFile) {
      myFile.println(cargardatos);
      myFile.flush();
      Serial.print(F("Guardado en SD: "));
      Serial.println(cargardatos);
 
      BT.println(cargardatos);   // mandar la línea de datos al celular mediante HC-05
 
    } else {
      Serial.println(F("Archivo no disponible. Reintentando abrir..."));
      abrirArchivoNuevo(Rtc.GetDateTime());
 
      // Intentar de nuevo tras reabrir
      if (myFile) {
        myFile.println(cargardatos);
        myFile.flush();
        Serial.println(F("Escritura exitosa tras recuperación."));
 
        BT.println(cargardatos); //también mandamos por BT después de recuperar
 
      } else {
        Serial.println(F("ERROR: Escritura fallida. No se pudo recuperar SD."));
 
        BT.println("ERROR_SD"); // aviso de error por BT si ni la SD responde
      }
    }
  }
}
 
 

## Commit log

2025-11-13 Entrega Final: Archivos completos y estructura organizada (Informe, Código, STL).
    [20251022.CSV, Carcasa_Estacion.stl]
2025-11-13 Se añadió PDF de Bitacoras y se actualizó el README.
